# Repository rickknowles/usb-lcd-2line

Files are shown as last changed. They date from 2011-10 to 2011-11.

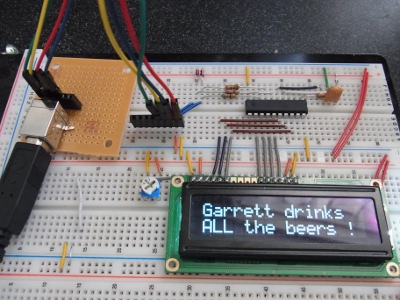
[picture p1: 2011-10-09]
photo.jpg

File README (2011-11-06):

USB control for a 2 line HD44870 style LCD display.

(for photo of breadboarded trial, see https://github.com/rickknowles/usb-lcd-2line/blob/master/photo.jpg)

Uses:
 * V-USB for the AVR microcontroller firmware (driving the LCD)
 * Peter Fleury's LCD control libraries on AVR
 * libusb for windows/mac/linux host side control software

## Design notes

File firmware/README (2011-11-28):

Firmware for the USB-LCD device

Steps:
 1. cd firmware
 2. Edit Makefile avrdude settings for your programmer (USBTiny, stk500, etc)
 3. Connect AVR programmer to chip
 4. make clean flash fuse

If you have trouble on your version of GCC for avr getting it less than 2KB 
compiled size, try just directly burning the main.hex file included in the 
checkout directly with avrdude.

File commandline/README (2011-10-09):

Command line control software for the LCD USB device

Steps:
 1. cd commandline
 2. make clean all
 3. sudo ./set-lcd "Mary had a little lamb"
 4. sudo ./set-lcd (to clear)

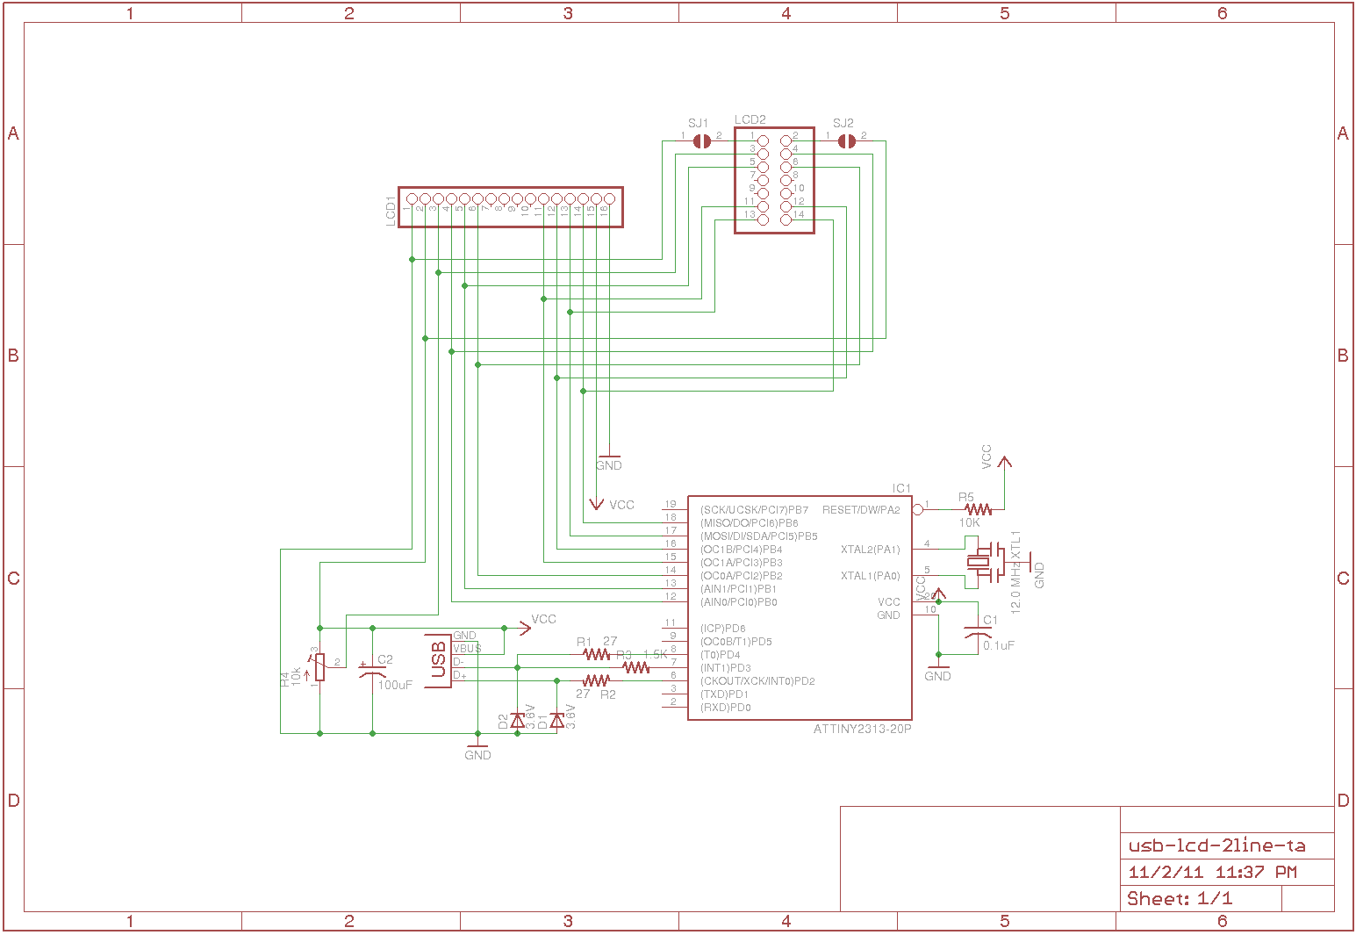
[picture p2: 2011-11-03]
circuit/usb-lcd-2line-schematic.png

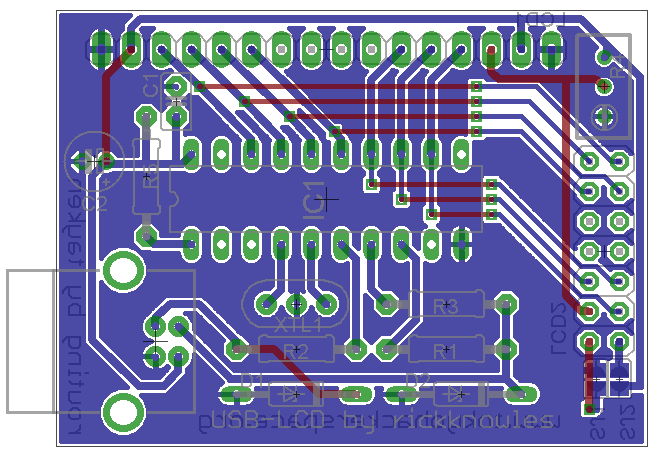
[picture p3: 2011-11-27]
circuit/usb-lcd-2line-pcb.png

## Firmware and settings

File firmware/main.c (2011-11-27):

/* Name: main.c
 * Project: control an LCD from a USB command line
 * Author: Rick Knowles
 * Creation Date: 2011-10-06
 * Tabsize: 4
 * License: GNU GPL v2 (see License.txt)
 * (modified from v-usb example custom-class)
 */

#include <avr/io.h>
#include <avr/wdt.h>
#include <avr/interrupt.h>  /* for sei() */
#include <util/delay.h>     /* for _delay_ms() */

#include <avr/pgmspace.h>   /* required by usbdrv.h */
#include "lcd.h"
#include "usbdrv.h"
#include "requests.h"

#define ROW_LENGTH  32

uchar bytesRemaining;

/* ------------------------------------------------------------------------- */
/* ----------------------------- USB interface ----------------------------- */
/* ------------------------------------------------------------------------- */

usbMsgLen_t usbFunctionSetup(uchar data[8])
{
    usbRequest_t *rq = (void *)data;
    if (rq->bRequest == CUSTOM_RQ_SHOW_MSG) {
        lcd_clrscr();
        bytesRemaining = rq->wLength.word;  // store the amount of data requested
        if (bytesRemaining > ROW_LENGTH) {
            // limit to buffer size
            bytesRemaining = ROW_LENGTH;
        }
        return USB_NO_MSG;
    } else if (rq->bRequest == CUSTOM_RQ_CLEAR) {
        lcd_clrscr();
        bytesRemaining = 0;
    }
    return 0;   /* default for not implemented requests: return no data back to host */
}

uchar usbFunctionWrite(uchar *data, uchar len)
{
    uchar i;
    if(len > bytesRemaining)                // if this is the last incomplete chunk
        len = bytesRemaining;               // limit to the amount we can store
    bytesRemaining -= len;
    for(i = 0; i < len; i++) {
        lcd_putc(data[i]);
    }
    return  ( bytesRemaining == 0);
}
/* ------------------------------------------------------------------------- */
int __attribute__((noreturn)) main(void)
{
    wdt_enable(WDTO_1S);

    lcd_init(LCD_DISP_ON);
    lcd_clrscr();
    lcd_puts("USB LCD");
    lcd_gotoxy(0,1);
    lcd_puts("Connecting");

    usbInit();
    usbDeviceDisconnect();  /* enforce re-enumeration, do this while interrupts are disabled! */

    _delay_ms(250);
    wdt_reset();
    usbDeviceConnect();
    lcd_gotoxy(0,1);
    lcd_puts("Ready     ");

    sei();
    for(;;){                /* main event loop */
        wdt_reset();
        usbPoll();
    }
}

/* ------------------------------------------------------------------------- */

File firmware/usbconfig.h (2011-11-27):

/* Name: usbconfig.h
 * Project: V-USB, virtual USB port for Atmel's(r) AVR(r) microcontrollers
 * Author: Christian Starkjohann
 * Creation Date: 2005-04-01
 * Tabsize: 4
 * Copyright: (c) 2005 by OBJECTIVE DEVELOPMENT Software GmbH
 * License: GNU GPL v2 (see License.txt), GNU GPL v3 or proprietary (CommercialLicense.txt)
 * This Revision: $Id: usbconfig-prototype.h 785 2010-05-30 17:57:07Z cs $
 */

#ifndef __usbconfig_h_included__
#define __usbconfig_h_included__

/*
General Description:
This file is an example configuration (with inline documentation) for the USB
driver. It configures V-USB for USB D+ connected to Port D bit 2 (which is
also hardware interrupt 0 on many devices) and USB D- to Port D bit 4. You may
wire the lines to any other port, as long as D+ is also wired to INT0 (or any
other hardware interrupt, as long as it is the highest level interrupt, see
section at the end of this file).
*/

/* ---------------------------- Hardware Config ---------------------------- */

#define USB_CFG_IOPORTNAME      D
/* This is the port where the USB bus is connected. When you configure it to
 * "B", the registers PORTB, PINB and DDRB will be used.
 */
#define USB_CFG_DMINUS_BIT      4
/* This is the bit number in USB_CFG_IOPORT where the USB D- line is connected.
 * This may be any bit in the port.
 */
#define USB_CFG_DPLUS_BIT       2
/* This is the bit number in USB_CFG_IOPORT where the USB D+ line is connected.
 * This may be any bit in the port. Please note that D+ must also be connected
 * to interrupt pin INT0! [You can also use other interrupts, see section
 * "Optional MCU Description" below, or you can connect D- to the interrupt, as
 * it is required if you use the USB_COUNT_SOF feature. If you use D- for the
 * interrupt, the USB interrupt will also be triggered at Start-Of-Frame
 * markers every millisecond.]
 */
#define USB_CFG_CLOCK_KHZ       (F_CPU/1000)
/* Clock rate of the AVR in kHz. Legal values are 12000, 12800, 15000, 16000,
 * 16500, 18000 and 20000. The 12.8 MHz and 16.5 MHz versions of the code
 * require no crystal, they tolerate +/- 1% deviation from the nominal
 * frequency. All other rates require a precision of 2000 ppm and thus a
 * crystal!
 * Since F_CPU should be defined to your actual clock rate anyway, you should
 * not need to modify this setting.
 */
#define USB_CFG_CHECK_CRC       0
/* Define this to 1 if you want that the driver checks integrity of incoming
 * data packets (CRC checks). CRC checks cost quite a bit of code size and are
 * currently only available for 18 MHz crystal clock. You must choose
 * USB_CFG_CLOCK_KHZ = 18000 if you enable this option.
 */

/* ----------------------- Optional Hardware Config ------------------------ */

#define USB_CFG_PULLUP_IOPORTNAME   D 
/* If you connect the 1.5k pullup resistor from D- to a port pin instead of
 * V+, you can connect and disconnect the device from firmware by calling
 * the macros usbDeviceConnect() and usbDeviceDisconnect() (see usbdrv.h).
 * This constant defines the port on which the pullup resistor is connected.
 */
#define USB_CFG_PULLUP_BIT          3
/* This constant defines the bit number in USB_CFG_PULLUP_IOPORT (defined
 * above) where the 1.5k pullup resistor is connected. See description
 * above for details.
 */

/* --------------------------- Functional Range ---------------------------- */
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

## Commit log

2011-10-15 added schematic (draft)
    [usb-lcd-2line.sch]
2011-10-16 modified the circuit to make it a little more layout friendly, fixed a couple of bugs
    [usb-lcd-2line.brd, usb-lcd-2line.sch]
2011-10-17 Changed the design, some pinswaps, for making layout friendly. Initial routing complete.
    [usb-lcd-2line-ta.brd, usb-lcd-2line-ta.sch]
2011-10-17 Lots of changes to board design: - Board size is smaller - Traces are thicker wherever possible - Isolation between ground plane and traces are increased - THS logo added - Component values removed t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
    [usb-lcd-2line-ta.brd, usb-lcd-2line-ta.sch]
2011-10-21 Changed USB connector to through hole type B, vertical clearence between USB and LCD is not know, we might have to move parts towards right a little.
    [usb-lcd-2line-ta.brd, usb-lcd-2line-ta.sch]
2011-10-21 Trace clearence issues solved, design passes DRC
    [usb-lcd-2line-ta.brd]
2011-10-26 Moved LCD to the bottom layer. This clears up top layer silkscreen and solves USB conn clearence issues.
    [usb-lcd-2line-ta.brd, usb-lcd-2line-ta.sch]
2011-11-01 Added second LCD header for a different footprint. Added solder jumpers in order to change VCC-GND pins with different LCDs.
    [usb-lcd-2line-ta.brd, usb-lcd-2line-ta.sch]
2011-11-01 Fixed a few airwires
    [usb-lcd-2line-ta.brd]
2011-11-02 added custom usb pid/vid pair and updated pin assignments in firmware to match taylan's board design
    [usb-lcd-2line.brd, usb-lcd-2line.sch]
2011-11-03 Added project name and attributions. Smaller than 5cm by 5cm. Final routing is finished. No place for THS logo, maybe a smaller logo.
    [usb-lcd-2line-ta.brd]
2011-11-06 added pcb design image
2011-11-06 THS link added. Text sizes shrinked in order to fit. Final routing check passed.
    [usb-lcd-2line-ta.brd]
2011-11-14 Gerber files are added for future productions.
    [usb-lcd-2line-ta.GBL, usb-lcd-2line-ta.GBO, usb-lcd-2line-ta.GBP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]
2011-11-14 Bill of materials added, final PCB image is added.
    [usb-lcd-2line-ta.brd, usb-lcd-2line-ta.sch]
2011-12-03 Revert "Enabled lcd scrolling again"
    This reverts commit 86b7f614c529683930a4e8c5026834acfe78cebe.
    [lcd.h]
